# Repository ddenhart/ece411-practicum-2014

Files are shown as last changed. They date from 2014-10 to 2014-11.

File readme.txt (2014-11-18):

// ECE 411 - readme
// ddenhart@pdx.edu
// jerscott@pdx.edu
// ccarmen@pdx.edu
// nsl2@pdx.edu

---2014.10.05 nslj---
   - Initial readme added
   - Added Carmen's decision matrix to repo
   - Added Carmen's project proposals to repo
   - Added Jeremiah's project proposals to repo
   - Added Nick's project proposals to repo
   - Added Deb's project proposals to repo
   - Added personal scoring to decision matrix
  
---2014.10.05 dd---
   - Added personal scoring to decision matrix
   - updated readme 

---2014.10.06 ccarmen---
   - Added personal scoring to decision matrix
   - Added approx. cost for my proposals
   - updated readme 

---2014.10.06 jerscott---
   - Added scores and proposal costs to decision matrix
   - updated readme

---2014.10.08 nslj---
   - Added theoretical block diagram for belt project   

---2014.10.09 ccarmen---
   - Added meeting minutes on Wiki 
   - Added decision matrix 
 
---2014.10.11 dd---
   - Added color sensing proposals

---2014.10.11 jerscott---
   - Added power and vague proposals

---2014.10.11 nslj---
   - Added system overview block diagram
   - New stage folder created

---2014.10.11 ccarmen—--
   - Added LED options powerpoint

---2014.10.12 nslj---
   - Reorganized file folders to reflect latest updates (for observers)
   - Added the alternate proposals write up for HW2

---2014.10.12 jerscott---
   - Added updated Practicum Proposal

---2014.10.14 dd---
   -Added musts, shoulds and mays to the logbook wiki
   -Added datasheets & product links to the wiki
   -Filled out class forms with team members and project name
   -Added Microcontroller and Color Sensor datasheets and purchasing links to wiki
   -Added In-System Programmer links to wiki

---2014.10.14 ccarmen---
   - Added 10/11/2014 meeting minutes
   - Added RGB LED strip datasheet & product link to the wiki

---2014.10.16 ccarmen---
   - Added AVR programmer option links on Datasheet & Product Links page

---2014.10.18 ccarmen---
   - Added 10/18/2014 meeting minutes on the Wiki

---2014.10.18 dd---
   -Updated Wiki to have the T10 name and added summary
   -Added Project Proposal and Decision Matrix Pages
   -Made organized Wiki sidebar

---2014.10.19 cc---
   -Added LED output drawing to provide info for the project schematic

---2014.10.20 dd---
   - Added Color Sensor block drawing
   
---2014.10.21 cc---
   - Carmen Ciobanu implemented the new Weekly Progress Report format on the Wiki (individual and team combined)

---2014.10.22 dd---
   -Added the template pages for the individual weekly reports on the wiki
   -Filled in the past weekly reports

---2014.10.23 dd---
  - installed avr studio to start learning
  - installed winavr to start learning

---2014.10.23 jerscott---
   - Added PDS
   
---2014.10.24 dd---
   - Color sensors, Micontrollers, test RGB leds, power supply and ISP parts arrived

---2014.10.24 nslj---
   - Added schematic rough draft
   - Added brief write up on adding custom libraries to EAGLE

---2014.10.24 nslj---
  - Added meeting minues and updated WPR

---2014.10.27 jerscott---
   - Uploaded Revision 2 PDS

---2014.10.27 dd---
   - Sync'd readme and wpr's
   - breadboard power adapter component and last of other connectors arrived

---2014.10.29 nslj---
   - Added preliminary schematic for turn in
   - Updated wiki with schematic info
 
---2014.11.02 dd---
   - Sync'd readme and wpr's

---2014.11.5 nslj---
   - preliminary board layout uploaded
   - updated wiki with layout info

---2014.11.6 nslj---
   - completely rerouted board with correct size traces
   - redid components based on preliminary bill of materials
   - new switch, new capacitors!

---2014.11.06 jerscott---
   - Provided feedback for project schematic and board layout

---2014.11.07 cc---
   - Provided feedback for project schematic and board layout
   - Identified all the parts needed for our board on Digi-Key website and found new parts for the "package not available or not in stock" case
   - Created BOM with extra fields for manufacturer name, manufacturer part number, Digi-Key part number and direct links to components on Digi-Key website
   - Ordered all components on the BOM
   
---2014.11.08 dd---
   - made part names readable on the board 
   - project schedule proposal

---2014.11.08 cc—--
   - Received all board components from Digi-key
   - Printed board layout and put components on top
   - Good match 
   - Finished editing final version of BOM document

---2014.11.08 nslj---
   - final layout candidate uploaded!
     --fixed airwire @ (1.30,1.05)
     --smashed/sized some test points in Schematic
     --updated dimension layer of board for better spacing of mounting holes
     --added teamname info to both tPlace and tSilk layers
     --png screenshots of final layout candidate?

---2014.11.09 cc—--
   - Created Project Schedule document from project schedule documents provided by each team member
  
---2014.11.10 dd---
   - Reviewed and fitted the Project Schedule
   
---2014.11.15 dd---
   - Added the color sensor uml activity view

---2014.11.15 cc—--
   - Added LED Output driver protocol sequence diagram

---2014.11.16 nslj---
   - Added L0 system view block diagram
   - Added L1 system view block diagram
   - Added L0 module view for subcomponents in system view

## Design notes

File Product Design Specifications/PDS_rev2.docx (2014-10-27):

Color Sensing Infinity Mirror

Practicum for ECE 411

Team 10:

Carmen Ciobanu

Deborah Denhart

Nick Lynch-Jonely

Jeremiah Scott

CONTENTS

1. INTRODUCTION
| 1.1 Practicum Requirement | 3
| 1.2 Overview | 3
| 1.3 Project Scope | 3
2. PROJECT DESCRIPTION
| 2.1 Product Summary | 3
| 2.2 Product Requirements | 4
3. USER REQUIREMENTS
| 3.1 User Interface | 6
| 3.2 User Manual | 6
4. DELETED REQUIREMENTS | | 6
5. APPENDICES | | 6
6. REVISIONS | | 6
| 6.1 Revision Marking | 6
| 6.2 Revision History | 6

1. INTRODUCTION

1.1 Practicum Requirement

A major portion of ECE 411 is the practicum project, which requires teams of students to design, build, and test a device that uses, at a minimum, a sensor, microcontroller, and an actuator. Additional requirements were specified to teams as well. These requirements shall henceforth be referred to as “marketing requirements.” The purpose of the product (henceforth referred to as “the product”) described in this document is to fulfill all marketing requirements.

1.2 Overview

LED art is popular and marketable, with interesting pieces going for hundreds of dollars. Our project decision was made with the intention to explore this attractive market. The product will be a tabletop infinity mirror that will respond to an object placed in the proximity of the mirror based on the object’s color.

The basic concept for the product was constrained and particularized by the skills of the individual team members as well as a desire for simplicity without sacrificing the demonstration of the technical acumen of the team.

1.3 Project Scope

It is the intention of the team to fulfill all of the “Must” requirements, some of the “Should” requirements, and some of the “May” requirements provided to the team by demonstrating competency through the design and construction of the product with particular interest in the following areas: bare-metal driver and software coding, use of digital and analog actuators, and creative power solutions.

The team will research and comply with best practices and standards of engineering throughout the process of creating the product.

2. PRODUCT DESCRIPTION

2.1 Product Summary

The product will be capable of sensing color. Based on the input, the product will adjust the output of an electric light array to match the detected color and it will also output a generated audio tone ~~corresponding to the color of the object~~. The product will be powered from a wall outlet and may also be powered by a rechargeable battery.

In order to make the product affordable to build and to increase the viability of the product as a commercial item, it is the intention of the team to design the product such that the total cost of components is no more that $80.

2.2 Product Requirements

System | Marketing Requirements | Engineering Requirements | Justification
Physical | 4 | 1. The microcontroller will be mounted to a two layer PCB. A sensor may be mounted to a daughter board. | The given marketing requirements specify use of a two layer PCB for the microcontroller. Based on the color sensors researched and depending upon the physical configuration of the product, a daughter board may be required for the sensor.
| 7,11 | 2. All electronics should be enclosed within the product. | This is in keeping with the desired aesthetic of the product (a tabletop novelty) and fulfills the additional marketing requirement of being enclosed. This also helps ensure the safety of the product by enclosing any exposed electrical conductors.
Power | 2,3,9 | 1. The product should be powered by a wall outlet. | This is a simple and cost effective solution that allows the team to procure an over the counter power adapter and also grants the team the flexibility not afforded by some other solutions (USB) to power more complex outputs.
| 6,10 | 2. The product may be powered by a rechargeable battery in addition to a wall outlet. | This increases the novelty of the product while allowing the team also to demonstrate proficiency with more complex power solutions.
| 6,10 | 3. The product may be capable of being turned on and off without de-powering the product. | This increases the novelty of the product while allowing the team also to demonstrate proficiency with more complex power solutions.
| 11 | 4. The power supply should be able to supply at least 12W of power under both wall power and battery power. | Based on team research, 12W should be sufficient to supply all of the product’s power requirements. This also ensures the safety of the product by ensuring that the waste heat can de dissipated without damage to the enclosure.
Microcontroller | 3,5,8,10 | 1. The product should use a microcontroller such as the Atmel AVR ATMega328 or similar to interpret the input and control the outputs. | Use of this type of microcontroller fulfills several of the marketing requirements while also allowing the team to demonstrate proficiency in writing bare metal code. In addition, this type of microcontroller provides enough GPIO pins to give the team flexibility in choosing inputs and outputs.
Input | 1,6,8,9,10 | 1. The product should use a sensor that can detect color even when no additional source of light is present and be able to transfer this data to a microcontroller. The sensor may be a TCS34725 or similar. | This is necessary for fulfilling marketing requirements and will also allow for the demonstration of proficiency in writing device drivers.
Output | 2,5,6,8,9,10 | 1. The product should have a luminescent output that can be controlled by a microcontroller and is capable of producing a range of RGB outputs. The output should also be constrained by output of the power supply. The output may be a digital LED array or similar. | This is necessary for fulfilling marketing requirements and the overall aesthetic of the product. Research has indicated that a strand of digital LED pixels will meet these various requirements. This will also allow for demonstration of proficiency in writing device drivers.
| 2,7 | 2. The light output should have a max power rating of no greater than 10W. | Based on research of available power supplies and LED outputs, 10W should be sufficiently low power to allow for battery operation and to be safely enclosed.
| 2,6,9,10 | 3. The product should output a tone controlled by PWM that corresponds to the detected color on the input. | This adds novelty to the product and also allows for demonstration of the team’s ability to manage increased complexity.
| 2 | 4. The audio output should require no more than 2W of power. | Based on research of available power supplies, 2W should be sufficiently low power to allow for battery operation.
Software | 8,10 | 1. The product will be programmed with bare metal drivers such as I2C and SPI or similar. | This fulfills marketing requirements and allows for demonstration of team proficiency.

Base Marketing Requirements (These are MUST requirements.)

1—Have one or more inputs or sensors

2—Have one or more outputs or transducers

3—Have one or more processing modules that control some of the outputs based on the inputs

4—Use two layer PCB that is between 1 and 16 in²

5—Use components that can be hand soldered

11—The product must be safe.

Additional Marketing Requirements (These are SHOULD requirements.)

6—Be novel and interesting

7—Be packaged in an enclosure

8—Be “bare metal”

9—Have more advanced sensors and actuators

10—Demonstrate proficiencies of team members

3. USER REQUIREMENTS

3.1 User Interface

The product should be sufficiently simple that the user can operate it under normal conditions with no outside instruction. The device should be coded and constructed in such a way as to be fun for the user and rugged enough to stand up to prolonged use.

3.2 User Manual

This space shall be filled with user instruction for all conditions including those that might reasonably be encountered, but that are outside the ordinary.

4. DELETED REQUIREMENTS

System | Deletion Date | Engineering Requirements | Justification
None | None | None | None

5. APPENDICES

None.

6. REVISIONS

6.1 Revision Marking

Changes to the previous revision will be marked in the current revision. Additions and changes will be highlighted in yellow (Example) while deletions will be struck through and colored red (~~Example~~).

6.2 Revision History

Revision 1—10/23/2014: Original revision.

Revision 2—10/27/2014: Made additions and one deletion from the Product Description.

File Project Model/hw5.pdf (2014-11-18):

# T10: Color Sensing Infinity Mirror System Level Design: Functional Decomposition and UML Behavior Modeling

# Carmen Ciobanu Deborah Denhart Nick Lynch-Jonely Jeremiah Scott

1

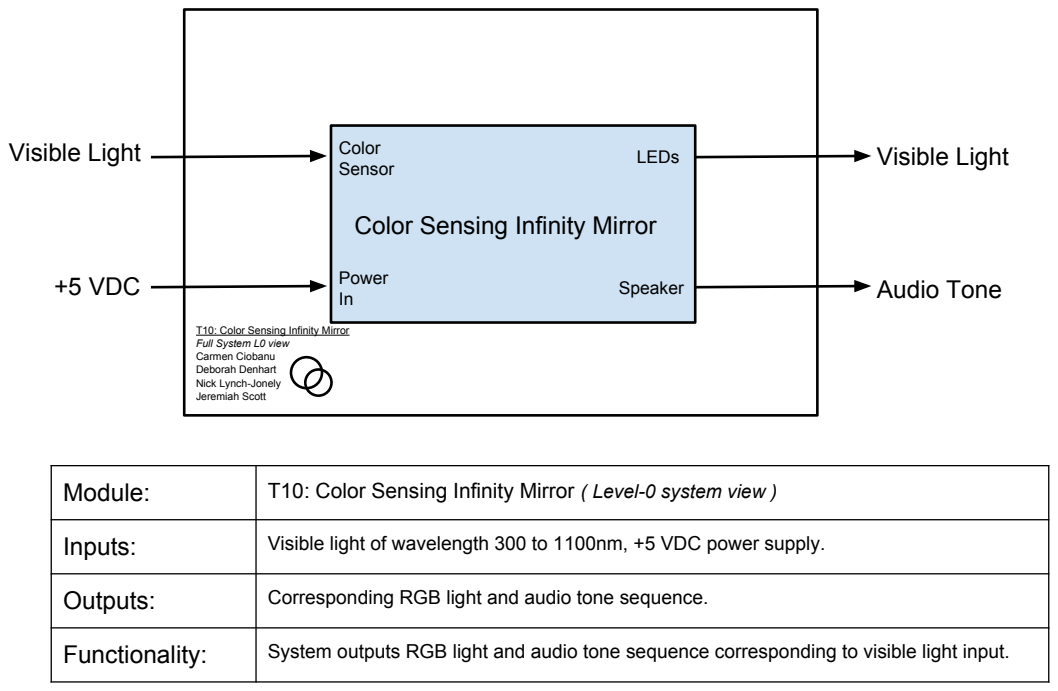
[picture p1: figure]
Color Sensor; Power In; LEDs; Speaker; Color Sensing Infinity Mirror; Visible Light; +5 VDC; Audio Tone; T10: Color Sensing Infinity Mirror Full System L0 view Carmen Ciobanu Deborah Denhart Nick Lynch-Jonely Jeremiah Scott

Module: | T10: Color Sensing Infinity Mirror ( Level-0 system view )
Inputs: | Visible light of wavelength 300 to 1100nm, +5 VDC power supply.
Outputs: | Corresponding RGB light and audio tone sequence.
Functionality: | System outputs RGB light and audio tone sequence corresponding to visible light input.

2

### Power 5V

12W

### Light Intensity

Color Sensor

Power supply

LED strip driver

Audio amplifier

Brief Description | System responds to color of ambient light input by generating a corresponding color LED output and selects a single audio tone from a bank of six corresponding audio sequences that are assigned a range of color.
Inputs | Light intensity reading: λ = 300 - 1100nm Power: 5VDC 12W
Outputs | LED emission: RGB color corresponding to light intensity input

Audio output: Tone sequence corresponding to light intensity input Microcontroller Unit

RGB LED strip

Audio out

96+1 byte
LED

### Visible Light

### Audio Tone

I²C Interface

T10: Color Sensing Infinity Mirror ( Level-1 system view )

T10: Color Sensing Infinity Mirror Full System L1 view
Carmen Ciobanu
Deborah Denhart
Nick Lynch-Jonely
Jeremiah Scott

3

### RGBC Control

Module: | T10: Color Sensor ( Level-0 module view )
Inputs: | Analog signal corresponding to detected light wavelengths of 300-1100nm, line A2 connected to white LED to assist with capturing light wavelength data. -0.5 to +3.8 VDC power supply.
Outputs: | Analog-to-digital conversion of IR filtered photodiode signal is transferred to double buffered data registers and sent to a two wire I²C serial bus directly connected to microcontroller unit, ~400kHz transmission rate.
Functionality: | 16-bit digital signal containing 4-bit representations of RGB levels plus a 4-bit clear register

# sent to an I²C interface IR filtered Photo Diodes

### Clear ADC

### Red ADC

### Green ADC

### Blue ADC

Clear Data

Red Data

Green Data

Blue Data

Interrupt

## I2C Interface

### INT

### SDA

## SCL

Level Shifted Power
Supply ~3.8V DC

# VCCAmbient Light intensity

white LED

A2

visible light

T10: Color Sensing Infinity Mirror Color Sensor L0 view
Carmen Ciobanu
Deborah Denhart
Nick Lynch-Jonely
Jeremiah Scott

4

## VCC

Module: | T10: RGB LED Strip ( Level-0 module view )
Inputs: | +5 VDC power supply (Vcc), 96+1 byte serial data, clock
Outputs: | x6 1-byte PWM channels driving x2 RGB LEDs in light range from 475 to 630nm wavelength, serial data, 1Hz clock signal
Functionality: | Drives RGB LED color from +/- 0.4V PWM signal input. Each driver chip is responsible for 2 LEDs. 96+1 bytes of information are sent to the first driver chip, 6 bytes are used for that chip and 90+1 bytes are passed on. Process continues for remaining driver chips.

### data

### clock data

### clock

### LED Current Driver

### LED Current Driver

r data

g data
b data

r data

g data
b data

### RGB LED

### RGB LED

r data

g data
b data

r data

g data
b data

### data

### clock

### x16 LED Current Driver x32 RGB LED

… x14

1

2
T10: Color Sensing Infinity Mirror RGB-LED strip L0 view
Carmen Ciobanu
Deborah Denhart
Nick Lynch-Jonely
Jeremiah Scott

5

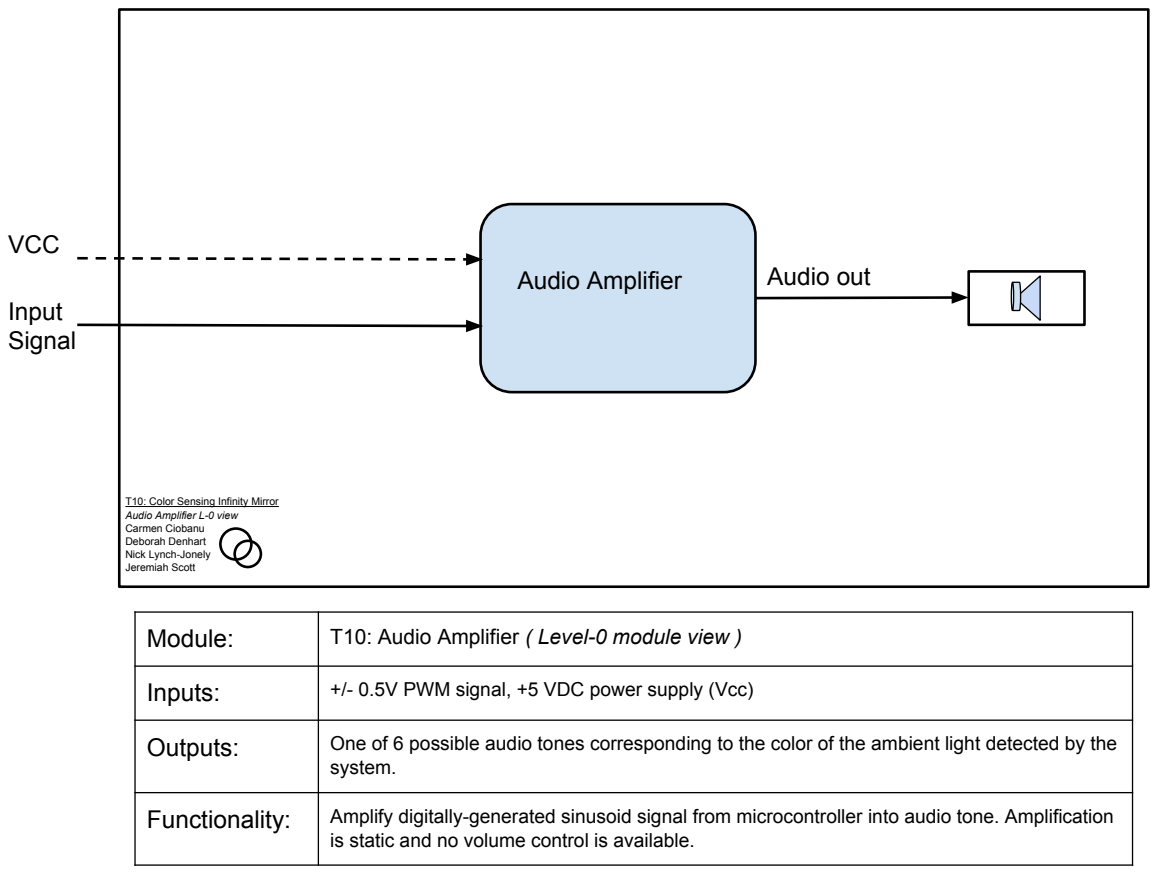
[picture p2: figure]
VCC; Input Signal; Audio Amplifier; Audio out; T10: Color Sensing Infinity Mirror Audio Amplifier L-0 view Carmen Ciobanu Deborah Denhart Nick Lynch-Jonely Jeremiah Scott

Module: | T10: Audio Amplifier ( Level-0 module view )
Inputs: | +/- 0.5V PWM signal, +5 VDC power supply (Vcc)
Outputs: | One of 6 possible audio tones corresponding to the color of the ambient light detected by the system.
Functionality: | Amplify digitally-generated sinusoid signal from microcontroller into audio tone. Amplification is static and no volume control is available.

6

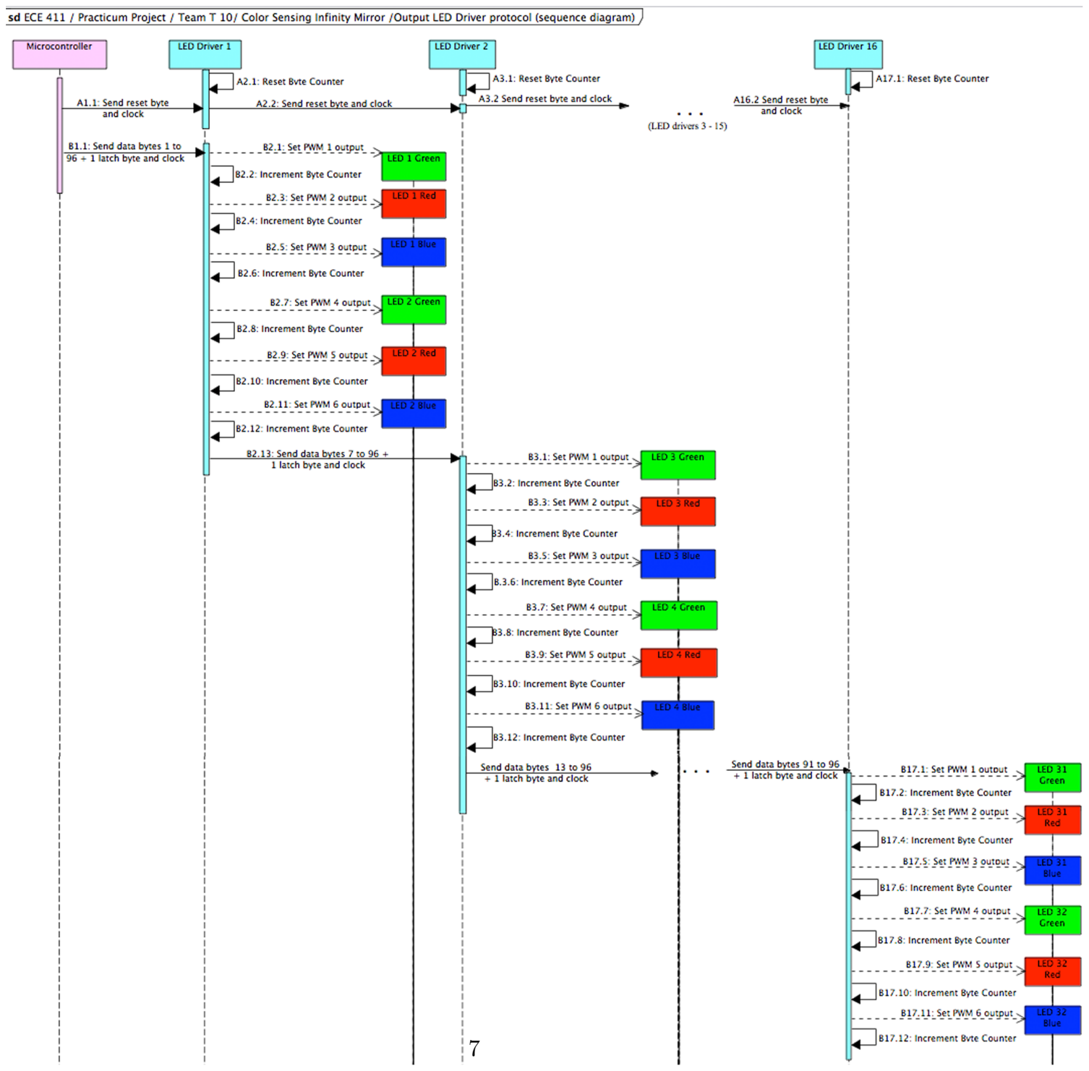
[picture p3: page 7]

7

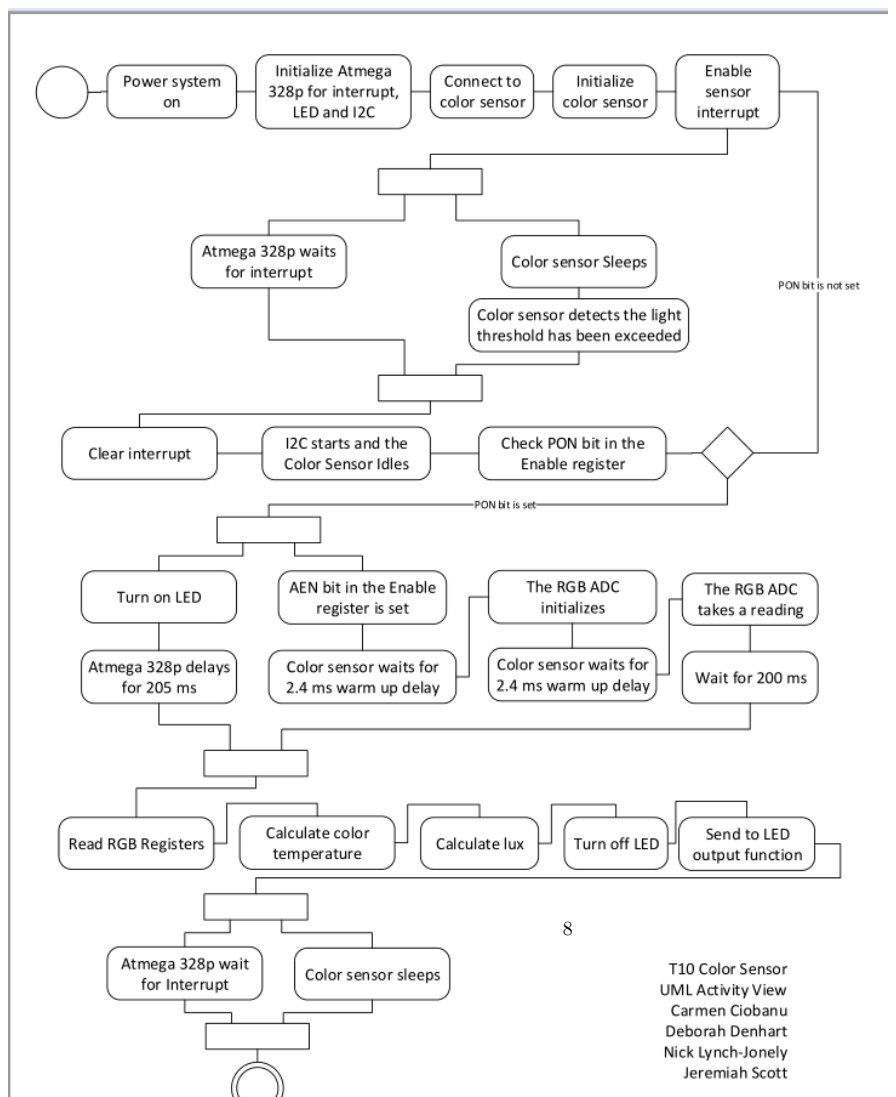
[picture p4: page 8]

8

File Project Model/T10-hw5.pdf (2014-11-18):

# T10: Color Sensing Infinity Mirror System Level Design: Functional Decomposition and UML Behavior Modeling

# Carmen Ciobanu Deborah Denhart Nick Lynch-Jonely Jeremiah Scott

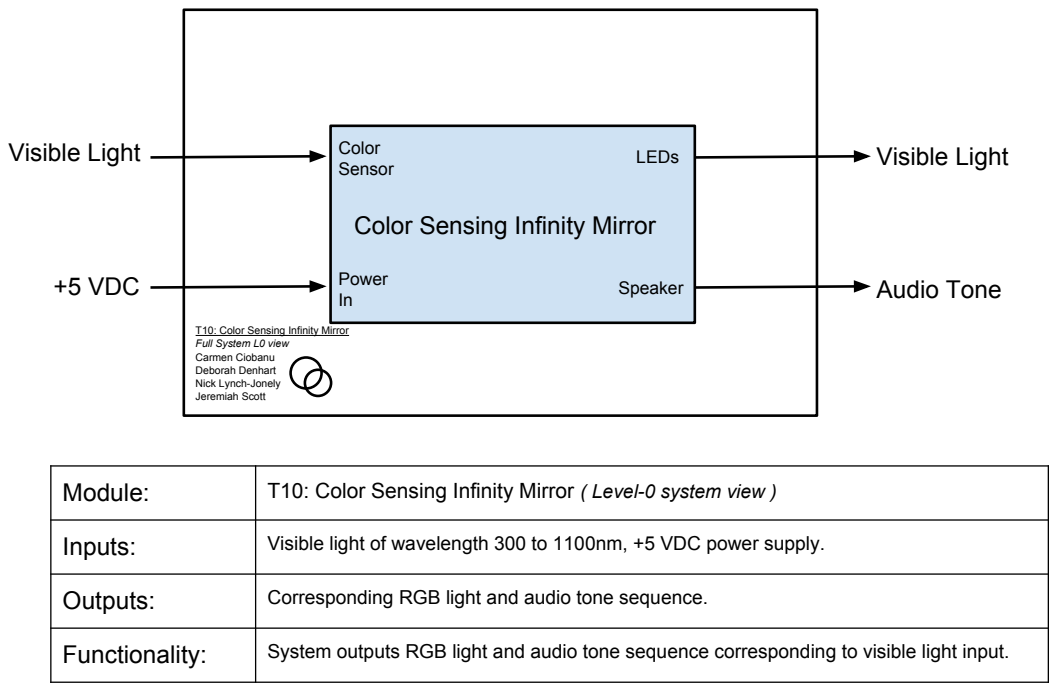
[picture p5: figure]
Color Sensor; Power In; LEDs; Speaker; Color Sensing Infinity Mirror; Visible Light; +5 VDC; Audio Tone; T10: Color Sensing Infinity Mirror Full System L0 view Carmen Ciobanu Deborah Denhart Nick Lynch-Jonely Jeremiah Scott

Module: | T10: Color Sensing Infinity Mirror ( Level-0 system view )
Inputs: | Visible light of wavelength 300 to 1100nm, +5 VDC power supply.
Outputs: | Corresponding RGB light and audio tone sequence.
Functionality: | System outputs RGB light and audio tone sequence corresponding to visible light input.

### Power 5V

12W

### Light Intensity

Color Sensor

Power supply

LED strip driver

Audio amplifier

Brief Description | System responds to color of ambient light input by generating a corresponding color LED output and selects a single audio tone from a bank of six corresponding audio sequences that are assigned a range of color.
Inputs | Light intensity reading: λ = 300 - 1100nm Power: 5VDC 12W
Outputs | LED emission: RGB color corresponding to light intensity input

Audio output: Tone sequence corresponding to light intensity input Microcontroller Unit

RGB LED strip

Audio out

96+1 byte
LED

### Visible Light

### Audio Tone

I²C Interface

T10: Color Sensing Infinity Mirror ( Level-1 system view )

T10: Color Sensing Infinity Mirror Full System L1 view
Carmen Ciobanu
Deborah Denhart
Nick Lynch-Jonely
Jeremiah Scott

### RGBC Control

Module: | T10: Color Sensor ( Level-0 module view )
Inputs: | Analog signal corresponding to detected light wavelengths of 300-1100nm, line A2 connected to white LED to assist with capturing light wavelength data. -0.5 to +3.8 VDC power supply.
Outputs: | Analog-to-digital conversion of IR filtered photodiode signal is transferred to double buffered data registers and sent to a two wire I²C serial bus directly connected to microcontroller unit, ~400kHz transmission rate.
Functionality: | 16-bit digital signal containing 4-bit representations of RGB levels plus a 4-bit clear register

# sent to an I²C interface IR filtered Photo Diodes

### Clear ADC

### Red ADC

### Green ADC

### Blue ADC

Clear Data

Red Data

Green Data

Blue Data

Interrupt

## I2C Interface

### INT

### SDA

## SCL

Level Shifted Power
Supply ~3.8V DC

# VCCAmbient Light intensity

white LED

A2

visible light

T10: Color Sensing Infinity Mirror Color Sensor L0 view
Carmen Ciobanu
Deborah Denhart
Nick Lynch-Jonely
Jeremiah Scott

## VCC

Module: | T10: RGB LED Strip ( Level-0 module view )
Inputs: | +5 VDC power supply (Vcc), 96+1 byte serial data, clock
Outputs: | x6 1-byte PWM channels driving x2 RGB LEDs in light range from 475 to 630nm wavelength, serial data, 1Hz clock signal
Functionality: | Drives RGB LED color from +/- 0.4V PWM signal input. Each driver chip is responsible for 2 LEDs. 96+1 bytes of information are sent to the first driver chip, 6 bytes are used for that chip and 90+1 bytes are passed on. Process continues for remaining driver chips.

### data

### clock data

### clock

### LED Current Driver

### LED Current Driver

r data

g data
b data

r data

g data
b data

### RGB LED

### RGB LED

r data

g data
b data

r data

g data
b data

### data

### clock

### x16 LED Current Driver x32 RGB LED

… x14

1

2
T10: Color Sensing Infinity Mirror RGB-LED strip L0 view
Carmen Ciobanu
Deborah Denhart
Nick Lynch-Jonely
Jeremiah Scott

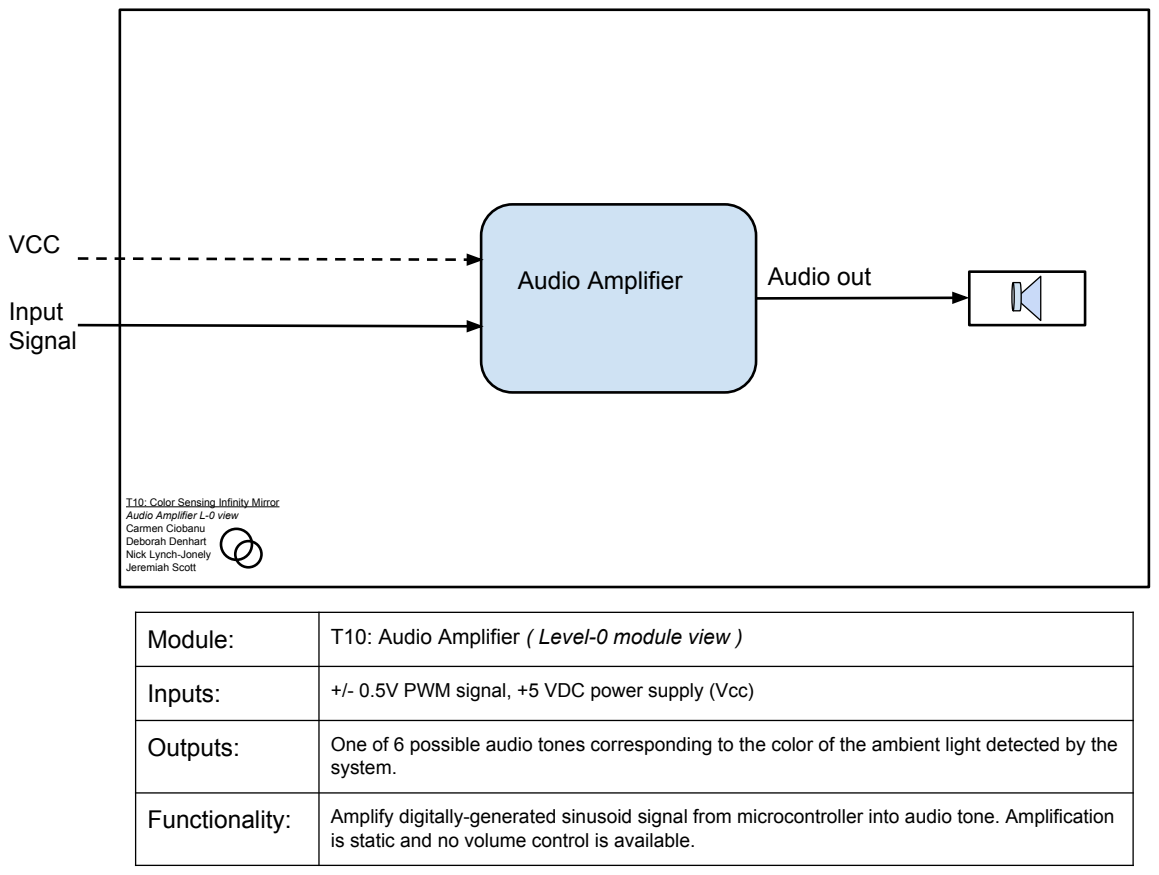
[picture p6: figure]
VCC; Input Signal; Audio Amplifier; Audio out; T10: Color Sensing Infinity Mirror Audio Amplifier L-0 view Carmen Ciobanu Deborah Denhart Nick Lynch-Jonely Jeremiah Scott

Module: | T10: Audio Amplifier ( Level-0 module view )
Inputs: | +/- 0.5V PWM signal, +5 VDC power supply (Vcc)
Outputs: | One of 6 possible audio tones corresponding to the color of the ambient light detected by the system.
Functionality: | Amplify digitally-generated sinusoid signal from microcontroller into audio tone. Amplification is static and no volume control is available.

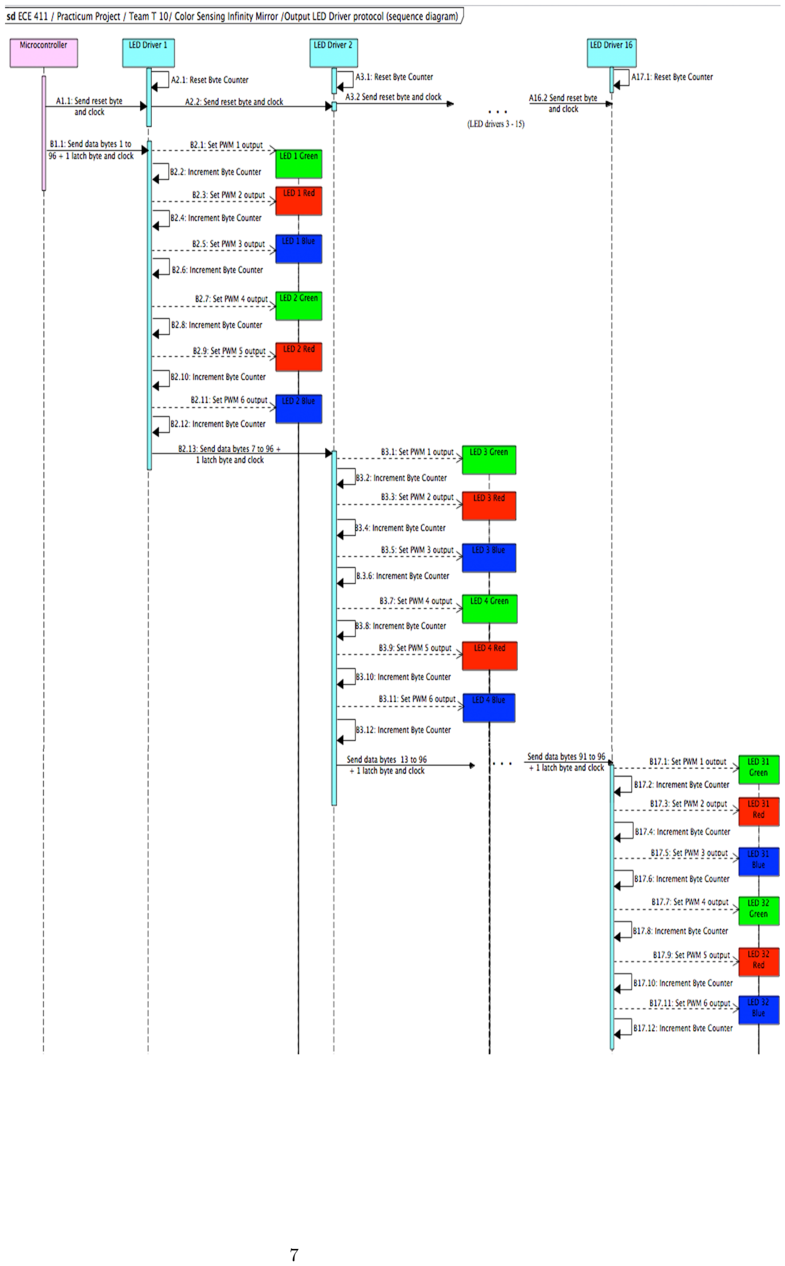
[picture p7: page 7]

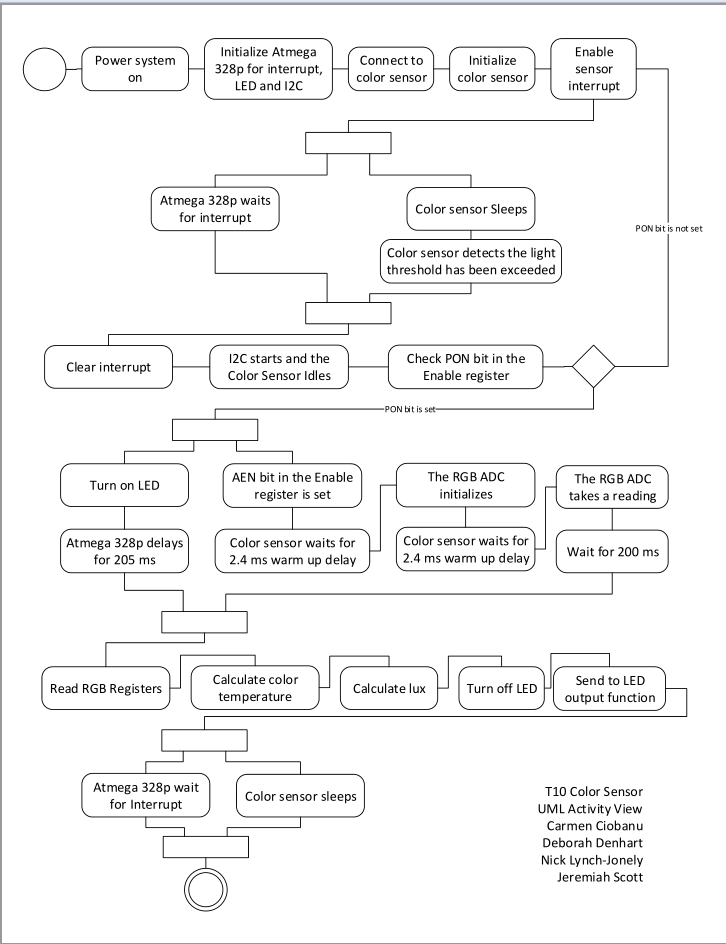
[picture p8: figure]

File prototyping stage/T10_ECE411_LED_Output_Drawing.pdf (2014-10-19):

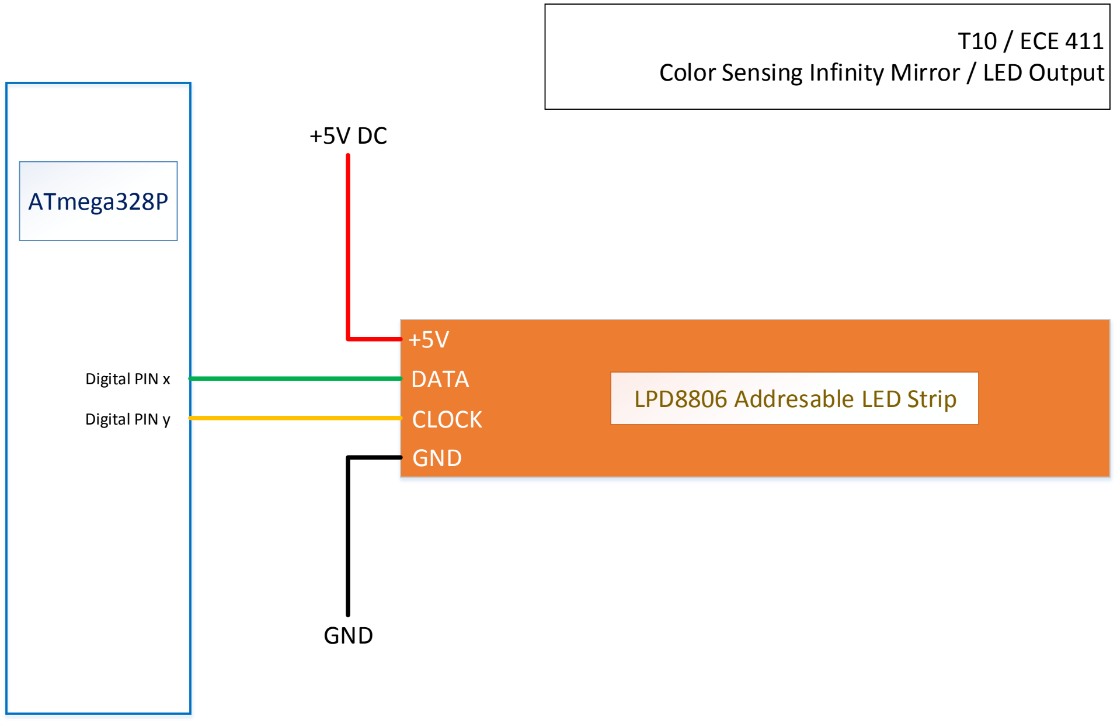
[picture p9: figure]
ATmega328P; DATA; CLOCK GND; LPD8806 Addresable LED Strip; GND; Digital PIN x; Digital PIN y; T10 / ECE 411

Color Sensing Infinity Mirror / LED Output

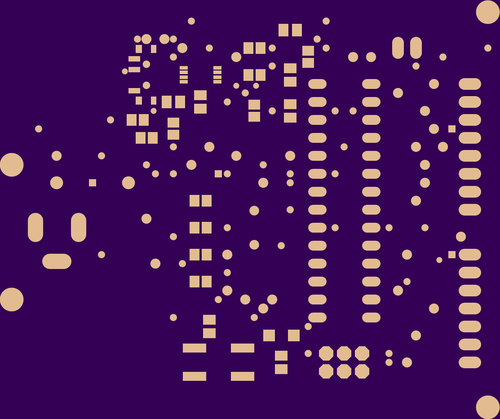
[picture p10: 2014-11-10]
Schematic/oshpark renders/topmask.png

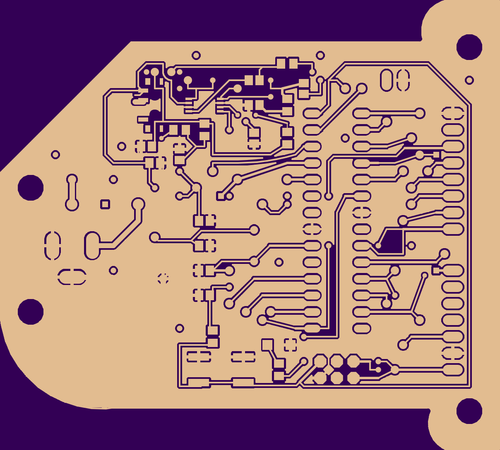
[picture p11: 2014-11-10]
Schematic/oshpark renders/toplayer.png

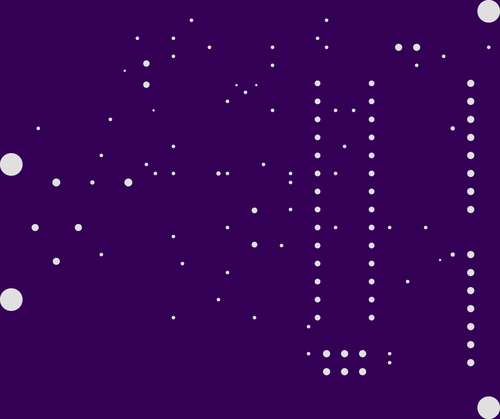
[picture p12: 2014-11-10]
Schematic/oshpark renders/drills.png

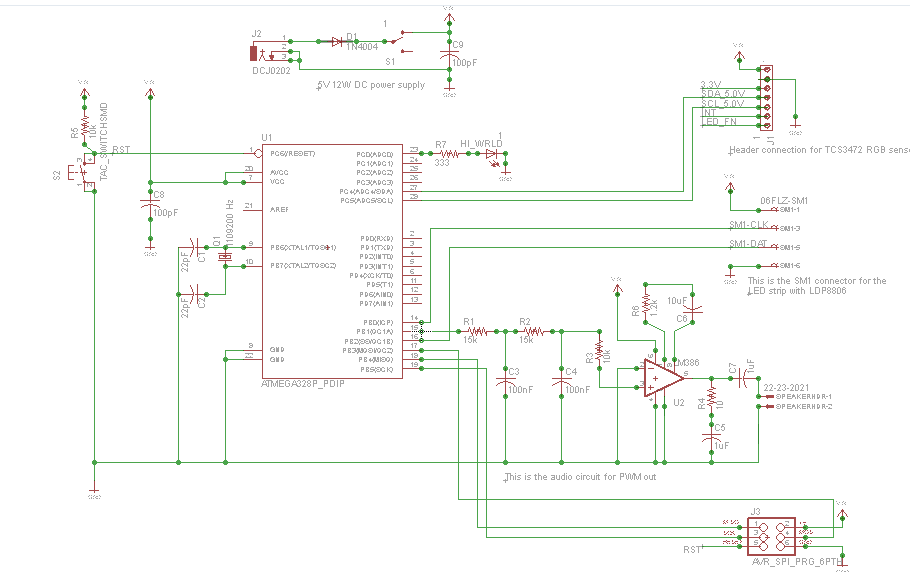
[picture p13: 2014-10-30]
Schematic/preliminaryschematic_v1_01.png

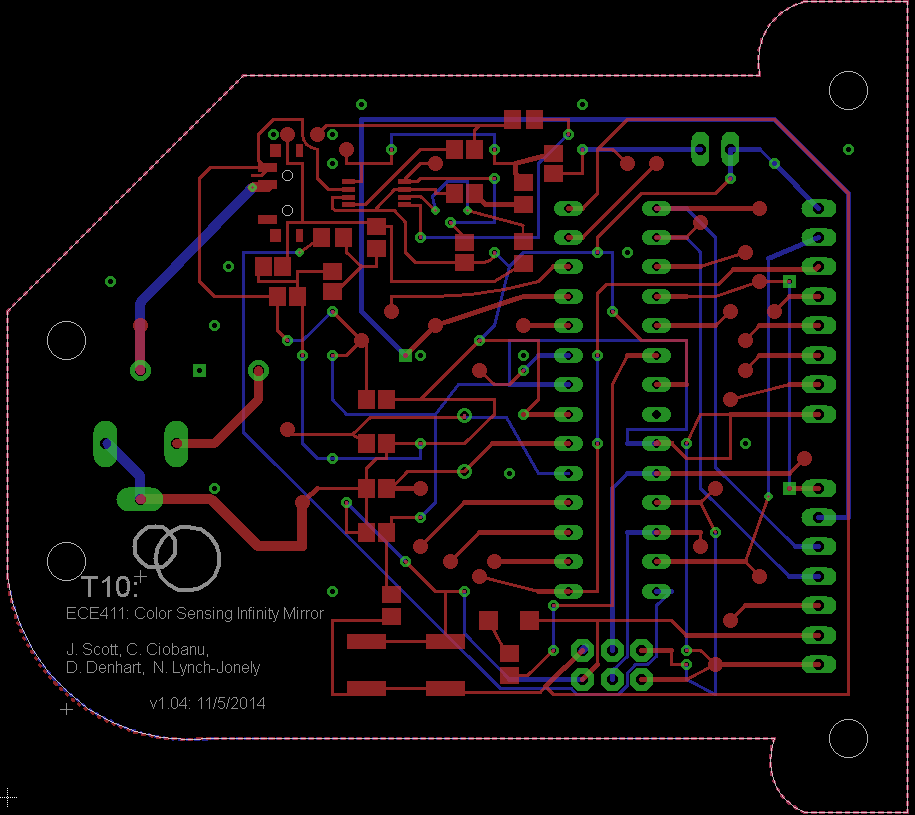
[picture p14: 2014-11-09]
Schematic/board_layout_final1.png

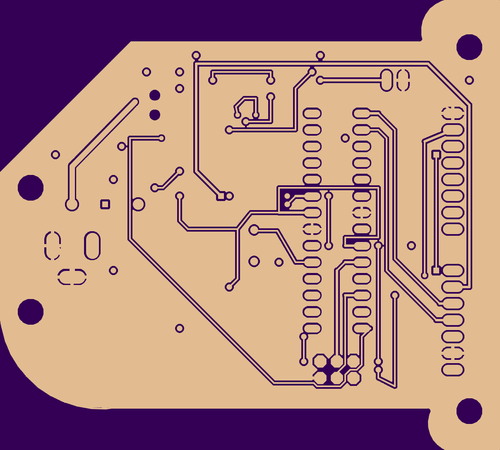
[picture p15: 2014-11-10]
Schematic/oshpark renders/bottomlayer.png

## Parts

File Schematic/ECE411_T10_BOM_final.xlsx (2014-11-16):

 |  |  |  | ECE411 Practicum T10 BOM for Infinity Mirror Project
Quantity | Part Number | Value | Package | Description | Manufacturer | Manufacturer Part Number | Distributor | Distributor Part Number | Cost Each | Cost Extended | Product Link
1 | JP1 |  | 1X08 | PIN HEADER | Sullins Connector Solutions | PPTC081LFBN-RC | Digi-Key | S7006-ND | $0.860 | $0.86 | Product Link (http://www.digikey.com/product-search/en?vendor=0&keywords=S7006-ND)
1 | HI_WRLD | 1 | SML1206 | LED | Lite-On Inc | LTST-C150KGKT | Digi-Key | 160-1404-1-ND | $0.390 | $0.39 | Product Link (http://www.digikey.com/product-detail/en/LTST-C150KGKT/160-1404-1-ND/386759)
1 | J1 | 1 | 10X07MTA | AMP connector | TE Connectivity | 640456-7 | Digi-Key | A19472-ND | $0.360 | $0.36 | Product Link (http://www.digikey.com/product-detail/en/640456-7/A19472-ND/259012)
1 | S1 | 1 | SWITCH-SPST-SMD-A | SPDT Switch | Apem Inc | MA12RTR | Digi-Key | 679-1847-1-ND | $1.100 | $1.10 | Product Link (http://www.digikey.com/product-detail/en/MA12RTR/679-1847-1-ND/1973774)
1 | R6 | 1.2k | M0805 | RESISTOR, American symbol | Panasonic | ERJ-P6WF1201V | Digi-Key | P16886CT-ND | $0.840 | $0.84 | Product Link (http://www.digikey.com/product-detail/en/ERJ-P6WF1201V/P16886CT-ND/4964925)
1 | R4 | 10 | M0805 | RESISTOR, American symbol | Vishay Dale | RCA080510R0FKEA | Digi-Key | 541-2219-1-ND | $0.400 | $0.40 | Product Link (http://www.digikey.com/product-detail/en/RCA080510R0FKEA/541-2219-1-ND/4946872)
5 | C3, C4, C8, C10, C11 | 100nF | C0805 | CAPACITOR, American symbol | Kemet | C0805C104J5RACTU | Digi-Key | 399-1171-1-ND | $0.160 | $0.80 | Product Link (http://www.digikey.com/product-detail/en/C0805C104J5RACTU/399-1171-1-ND/411446)
2 | R3, R5 | 10k | M0805 | RESISTOR, American symbol | Panasonic | ERJ-6ENF1002V | Digi-Key | P10.0KCCT-ND | $0.100 | $0.20 | Product Link (http://www.digikey.com/product-detail/en/ERJ-6ENF1002V/P10.0KCCT-ND/119248)
2 | C6, C9 | 10uF | C0805 | CAPACITOR, American symbol | Kemet | C0805C106K8PACTU | Digi-Key | 399-4925-1-ND | $0.210 | $0.42 | Product Link (http://www.digikey.com/product-detail/en/C0805C106K8PACTU/399-4925-1-ND/1090920)
2 | R1, R2 | 15k | R0805 | RESISTOR, American symbol | Panasonic | ERJ-6ENF1502V | Digi-Key | P15.0KCCT-ND | $0.100 | $0.20 | Product Link (http://www.digikey.com/product-detail/en/ERJ-6ENF1502V/P15.0KCCT-ND/119312)
1 | D1 | 1N4004 | DO41-10 | DIODE | Fairchild Semiconductors | 1N4004 | Digi-Key | 1N4004FSCT-ND | $0.180 | $0.18 | Product Link (http://www.digikey.com/product-detail/en/1N4004/1N4004FSCT-ND/1626118?WT.z_cid=ref_octopart_dkc_buynow&site=us)
2 | C5, C7 | 1uF | C0805 | CAPACITOR, American symbol | Kemet | C0805C105J3RACTU | Digi-Key | 399-10060-1-ND | $1.030 | $2.06 | Product Link (http://www.digikey.com/product-detail/en/C0805C105J3RACTU/399-10060-1-ND/3739579)
1 | SPEAKERHDR | 22-23-2021 | 22-23-2021 | .100 (2.54mm) Center Header - 2 Pin" | Molex Inc | 22232021 | Digi-Key | WM4200-ND | $0.200 | $0.20 | Product Link (http://www.digikey.com/product-search/en?x=0&y=0&lang=en&site=us&keywords=22232021)
2 | C1, C2 | 22pF | C0805 | CAPACITOR, American symbol | Kemet | C0805C220J5GACTU | Digi-Key | 399-1113-1-ND | $0.100 | $0.20 | Product Link (http://www.digikey.com/product-detail/en/C0805C220J5GACTU/399-1113-1-ND/411388)
1 | R7 | 333 | M0805 | RESISTOR, American symbol | Panasonic | ERJ-6ENF3320V | Digi-Key | P332CCT-ND | $0.100 | $0.10 | Product Link (http://www.digikey.com/product-detail/en/ERJ-6ENF3320V/P332CCT-ND/118818)
1 | Q1 | 8.192 MHz | HC49/S | CRYSTAL | TXC CORPORATION | 9B-8.192MAAJ-B | Digi-Key | 887-1262-ND | $0.390 | $0.39 | Product Link (http://www.digikey.com/product-detail/en/9B-8.192MAAJ-B/887-1262-ND/2207682)
1 | U1 | ATMEGA328P_PDIP | DIL28-3 | uC used in the Arduino | Atmel | ATMEGA328P-PU | Digi-Key | ATMEGA328P-PU-ND | $3.740 | $3.74 | Product Link (http://www.digikey.com/product-detail/en/ATMEGA328P-PU/ATMEGA328P-PU-ND/1914589)
1 | J3 | AVR_SPI_PRG_6PTH | 2X3 | AVR ISP 6 Pin | 3M | 961206-6404-AR | Digi-Key | 3M9459-ND | $0.420 | $0.42 | Product Link (http://www.digikey.com/product-detail/en/961206-6404-AR/3M9459-ND/2071500)
1 | J2 | DCJ0202 | DCJ0202 | DC POWER JACK | CUI Inc | PJ-102AH | Digi-Key | CP-102AH-ND | $1.180 | $1.18 | Product Link (http://www.digikey.com/product-search/en?vendor=0&keywords=PJ-102AH)
1 | IC1 | LM386MM-1 | MMSOP08 | Low Voltage Audio Power Amplifier | Texas Instruments | LM386MMX-1/NOPB | Digi-Key | LM386MMX-1/NOPBCT-ND | $1.020 | $1.02 | Product Link (http://www.digikey.com/product-detail/en/LM386MMX-1%2FNOPB/LM386MMX-1%2FNOPBCT-ND/3526976)
1 | S2 | TAC_SWITCHSMD | TACTILE-SWITCH-SMD | Momentary Switch | Panasonic | EVQ-Q2B03W | Digi-Key | P12932SCT-ND | $0.400 | $0.40 | Product Link (http://www.digikey.com/product-detail/en/EVQ-Q2B03W/P12932SCT-ND/762922)
 |  |  |  |  |  |  |  |  |  | $15.46

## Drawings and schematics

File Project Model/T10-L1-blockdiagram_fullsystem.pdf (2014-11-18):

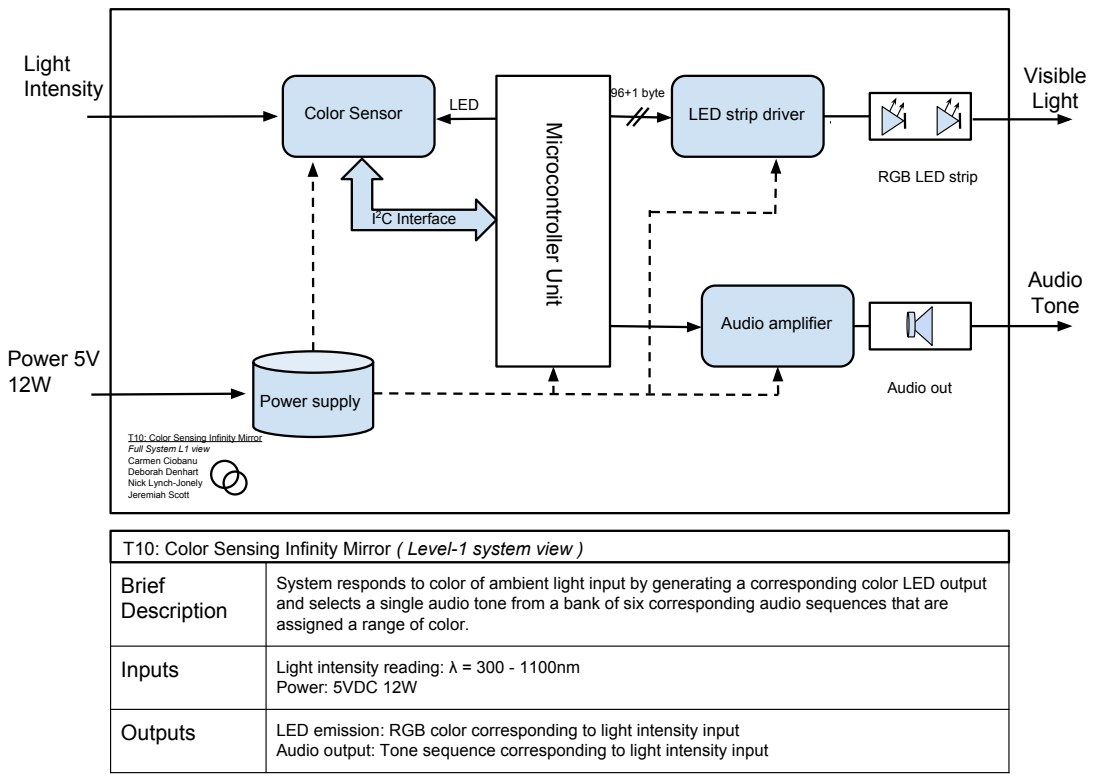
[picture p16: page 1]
Power 5V 12W; Light Intensity; Power supply; Audio amplifier; Audio out; 96+1 byte; LED; Visible Light; Audio Tone; 2C Interface

Color Sensor
Audio output: Tone sequence corresponding to light intensity input Microcontroller Unit

LED strip driver

RGB LED strip

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

T10: Color Sensing Infinity Mirror ( Level-1 system view )

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

Inputs | Light intensity reading: λ = 300 - 1100nm Power: 5VDC 12W

Outputs | LED emission: RGB color corresponding to light intensity input

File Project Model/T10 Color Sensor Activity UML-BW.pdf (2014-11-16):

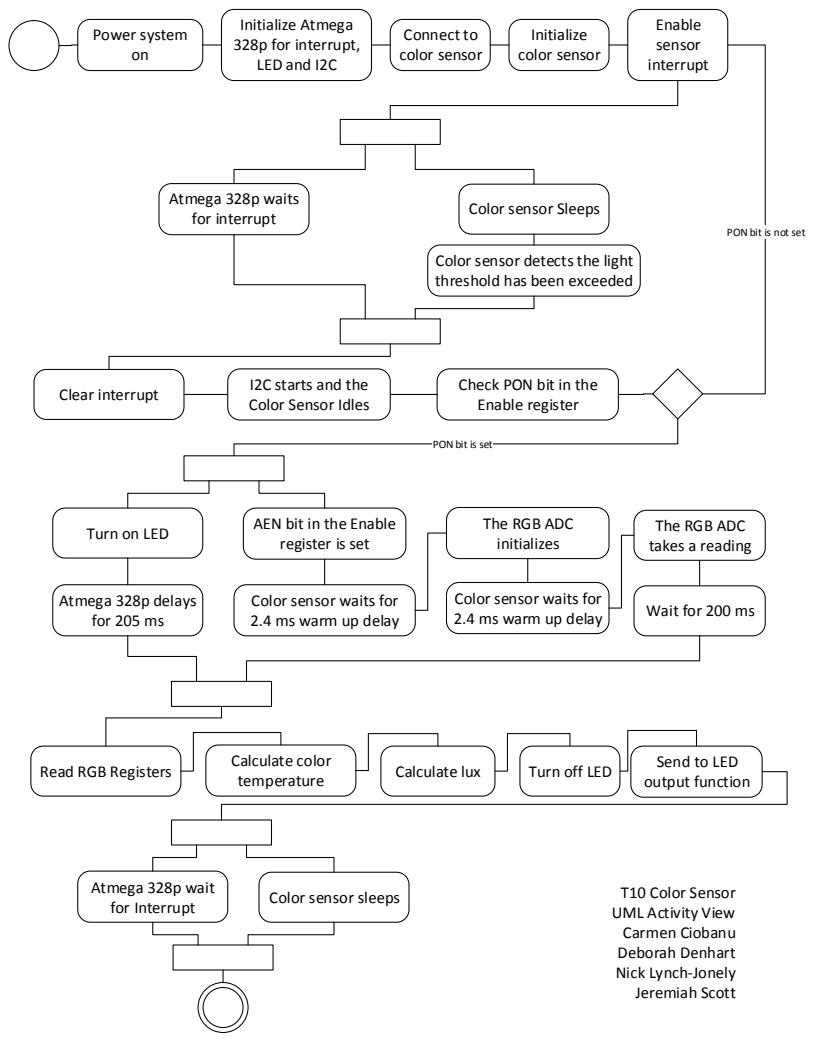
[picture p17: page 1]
Power system on; Initialize Atmega 328p for interrupt, LED and I2C; Connect to color sensor; Initialize color sensor; Enable sensor interrupt; Atmega 328p waits; for interrupt; Color sensor Sleeps; Clear interrupt; 2.4 ms warm up delay; Wait for 200 ms; Atmega 328p delays for 205 ms; Read RGB Registers; Calculate color; temperature; Calculate lux; Send to LED; output function; Atmega 328p wait; for Interrupt; Color sensor sleeps

PON bit is not set

Color sensor detects the light
threshold has been exceeded

I2C starts and the
Color Sensor Idles

Check PON bit in the
Enable register

PON bit is set

AEN bit in the Enable
register is set

The RGB ADC
initializes

takes a reading

Turn on LED

Color sensor waits for
2.4 ms warm up delay

Turn off LED

T10 Color Sensor
UML Activity View
Carmen Ciobanu
Deborah Denhart
Nick Lynch-Jonely
Jeremiah Scott

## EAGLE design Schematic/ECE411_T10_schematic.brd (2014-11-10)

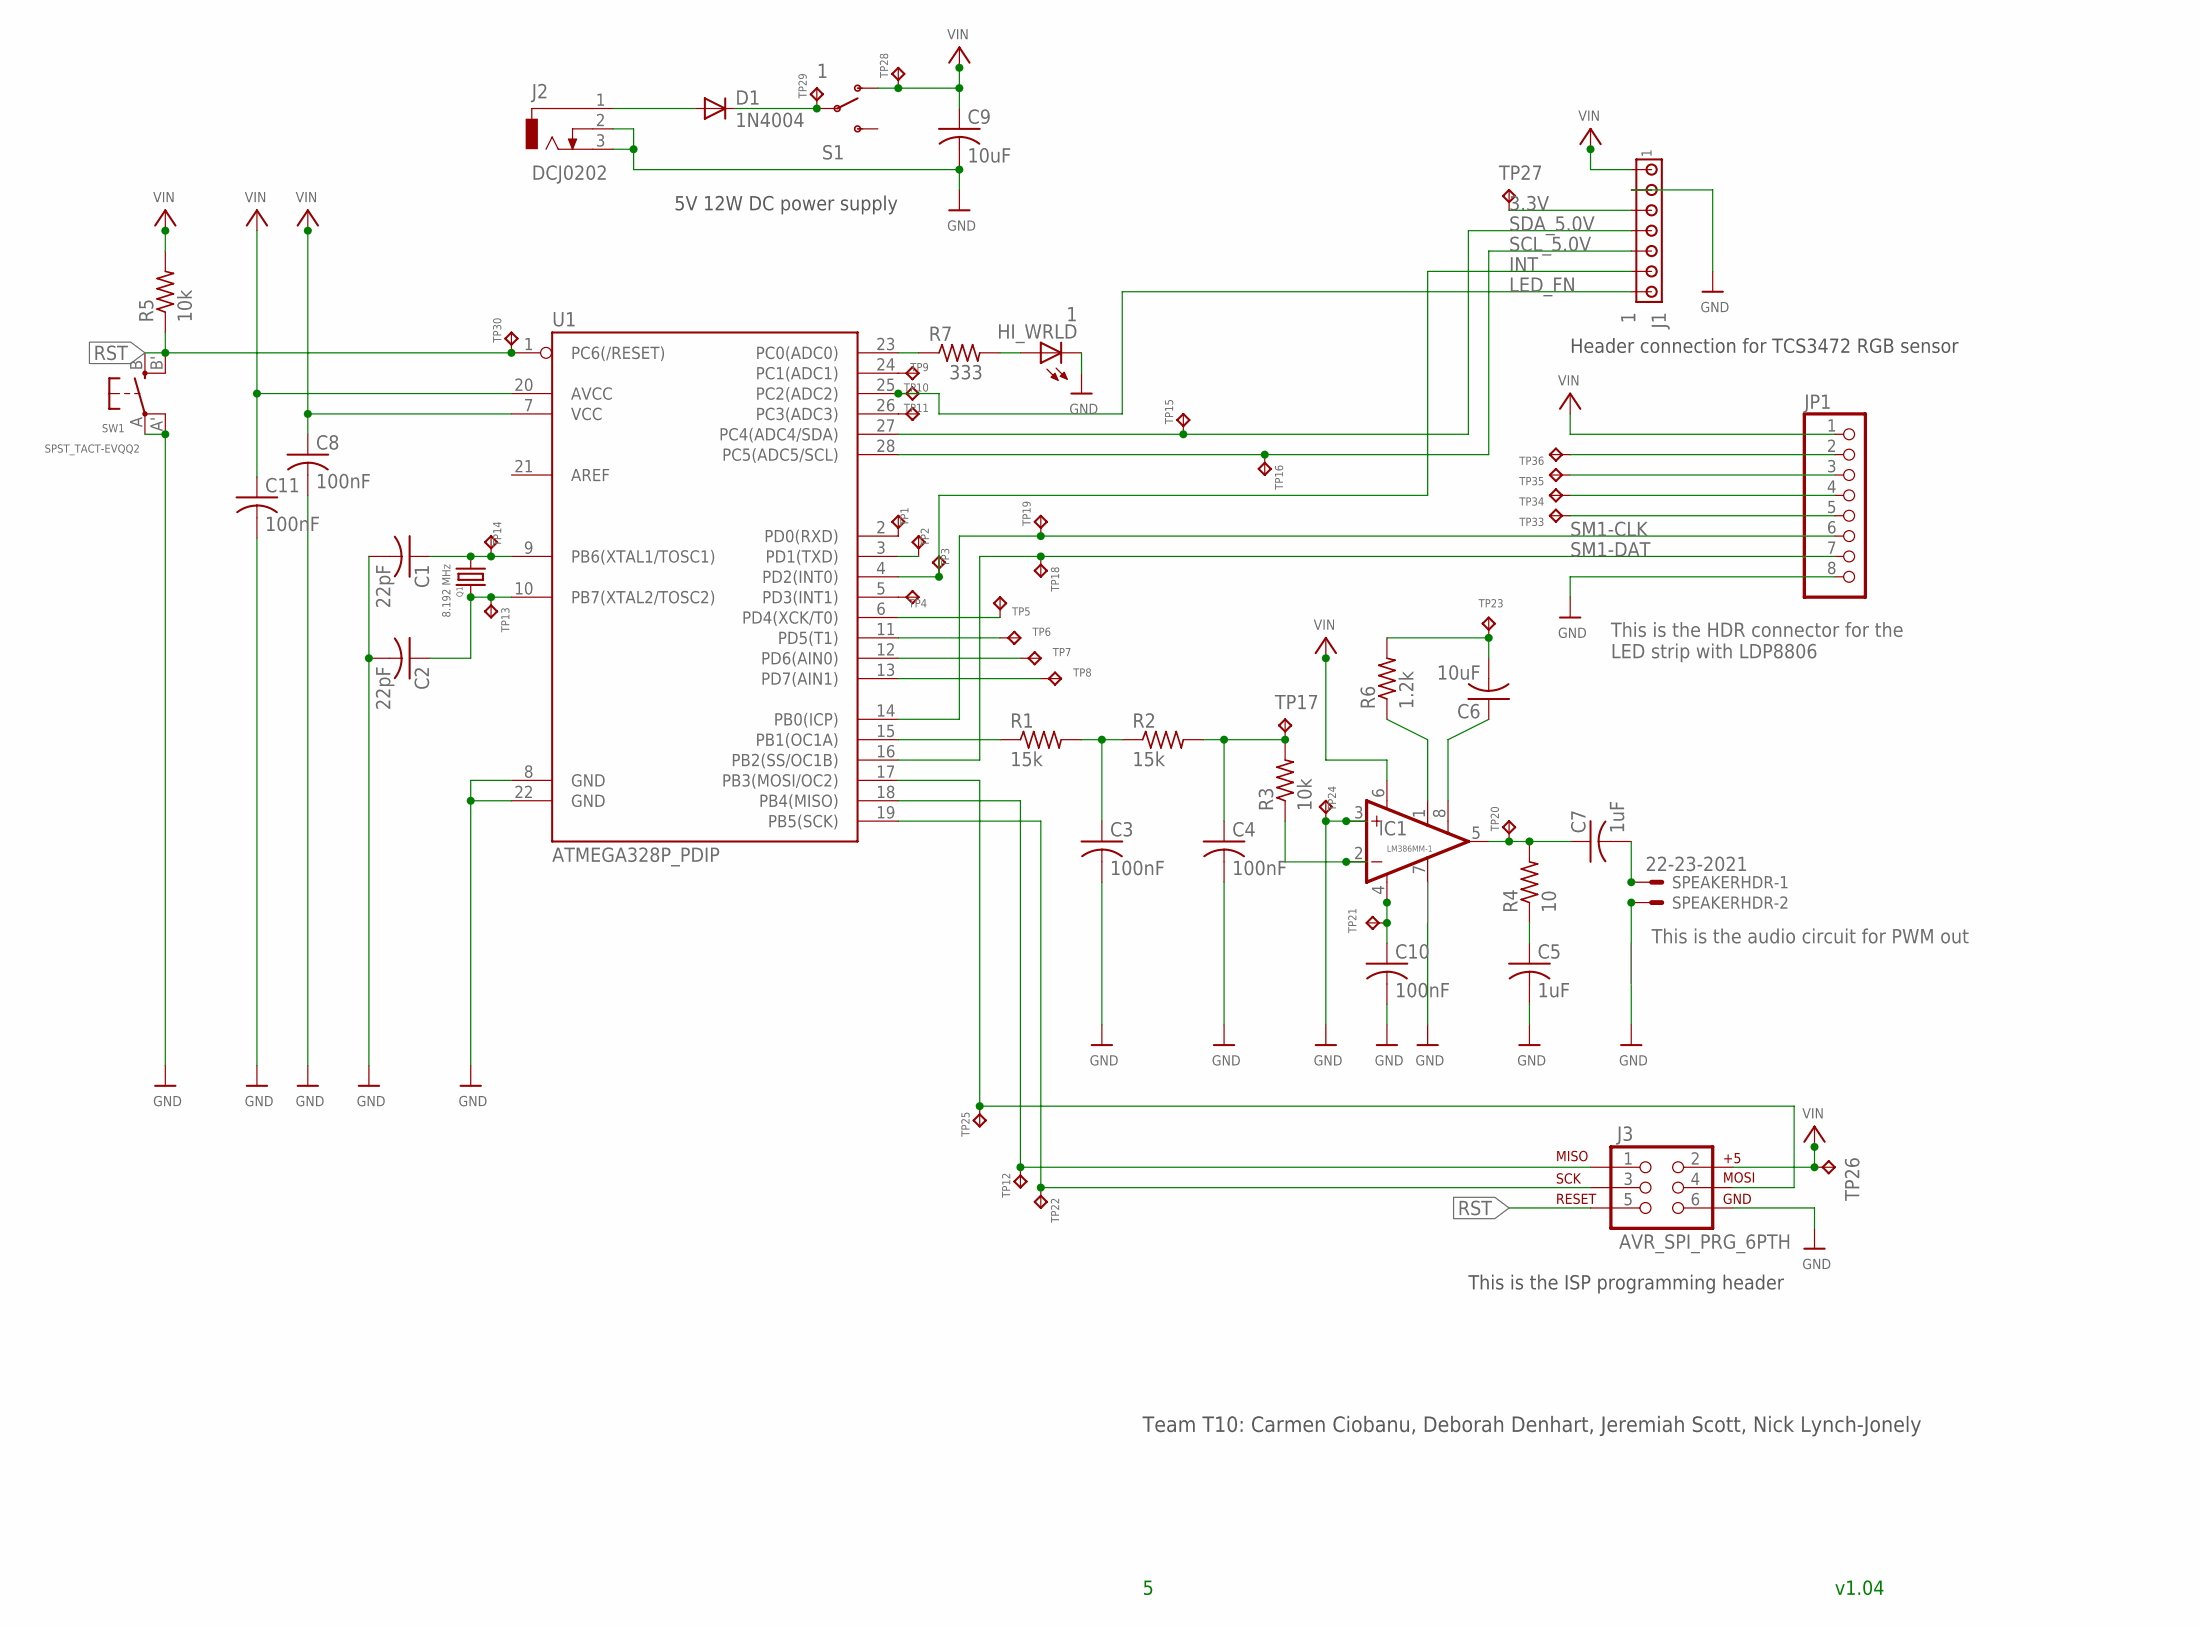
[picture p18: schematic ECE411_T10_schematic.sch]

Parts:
C1, C2: 22pF; C0805
C3, C4, C8, C10, C11: 100nF; C0805
C5, C7: 1uF; C0805
C6, C9: 10uF; C0805
D1: 1N4004; DO41-10
HI_WRLD: 1; SML1206
IC1: LM386MM-1; MMSOP08
J1: 1; 10X07MTA
J2: DCJ0202
J3: AVR_SPI_PRG_6PTH; 2X3
JP1: PINHD-1X8; 1X08
Q1: 8.192 MHz; HC49/S
R1, R2: 15k; M0805
R3, R5: 10k; M0805
R4: 10; M0805
R6: 1.2k; M0805
R7: 333; M0805
S1: 1; SWITCH-SPST-SMD-A
SPEAKERHDR: 22-23-2021
SW1: SPST_TACT-EVQQ2; EVQ-Q2
TP1, TP2, TP3, TP4, TP5, TP6, TP7, TP8, TP9, TP10, TP11, TP12, TP13, TP14, TP15, TP16, TP17, TP18, TP19, TP20, TP21, TP22, TP23, TP24, TP25, TP26, TP27, TP28, TP29, TP30, TP33, TP34, TP35, TP36: TPB1,27; B1,27
U1: ATMEGA328P_PDIP; DIL28-3

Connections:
3.3V: J1.3, TP27.TP
GND: C1.2, C2.2, C3.2, C4.2, C5.2, C8.2, C9.2, C10.2, C11.2, HI_WRLD.C, IC1.3 (+IN), IC1.7 (BYPASS), J1.2, J2.2, J2.3, J3.6, JP1.8, SPEAKERHDR.2, SW1.A, SW1.A' (P1), TP24.TP, U1.8 (GND), U1.22 (GND)
INT: J1.6, TP3.TP, U1.4 (PD2(INT0))
LED_FN: J1.7, TP10.TP, U1.25 (PC2(ADC2))
unnamed: C2.1, Q1.1, TP13.TP, U1.10 (PB7(XTAL2/TOSC2))
unnamed: C1.1, Q1.2, TP14.TP, U1.9 (PB6(XTAL1/TOSC1))
unnamed: IC1.1 (GAIN), R6.1
unnamed: R1.1, U1.15 (PB1(OC1A))
unnamed: C3.1, R1.2, R2.1
unnamed: C4.1, R2.2, R3.2, TP17.TP
unnamed: C6.1, IC1.8 (GAIN)
unnamed: IC1.2 (-IN), R3.1
unnamed: C5.1, R4.1
unnamed: R7.1, U1.23 (PC0(ADC0))
unnamed: C6.2, R6.2, TP23.TP
unnamed: C7.1, IC1.5 (OUT), R4.2, TP20.TP
unnamed: D1.A, J2.1
unnamed: C7.2, SPEAKERHDR.1
unnamed: D1.C, S1.2, TP29.TP
unnamed: TP1.TP, U1.2 (PD0(RXD))
unnamed: HI_WRLD.A, R7.2
unnamed: J3.3, TP22.TP, U1.19 (PB5(SCK))
unnamed: J3.1, TP12.TP, U1.18 (PB4(MISO))
unnamed: J3.4, TP25.TP, U1.17 (PB3(MOSI/OC2))
unnamed: TP5.TP, U1.6 (PD4(XCK/T0))
unnamed: TP2.TP, U1.3 (PD1(TXD))
unnamed: TP4.TP, U1.5 (PD3(INT1))
unnamed: TP6.TP, U1.11 (PD5(T1))
unnamed: TP7.TP, U1.12 (PD6(AIN0))
unnamed: TP8.TP, U1.13 (PD7(AIN1))
unnamed: TP9.TP, U1.24 (PC1(ADC1))
unnamed: TP11.TP, U1.26 (PC3(ADC3))
unnamed: C10.1, IC1.4 (GND), TP21.TP
unnamed: JP1.2, TP36.TP
unnamed: JP1.3, TP35.TP
unnamed: JP1.4, TP34.TP
unnamed: JP1.5, TP33.TP
RST: J3.5, R5.1, SW1.B (S), SW1.B' (S1), TP30.TP, U1.1 (PC6(/RESET))
SCL_5.0V: J1.5, TP16.TP, U1.28 (PC5(ADC5/SCL))
SDA_5.0V: J1.4, TP15.TP, U1.27 (PC4(ADC4/SDA))
SM1-CLK: JP1.6, TP19.TP, U1.14 (PB0(ICP))
SM1-DAT: JP1.7, TP18.TP, U1.16 (PB2(SS/OC1B))
VIN: C8.1, C9.1, C11.1, IC1.6 (VS), J1.1, J3.2, JP1.1, R5.2, S1.1 (O), TP26.TP, TP28.TP, U1.7 (VCC), U1.20 (AVCC)

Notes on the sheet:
This is the HDR connector for the LED strip with LDP8806
This is the audio circuit for PWM out
5V 12W DC power supply
Header connection for TCS3472 RGB sensor
Team T10: Carmen Ciobanu, Deborah Denhart, Jeremiah Scott, Nick Lynch-Jonely
v1.04
This is the ISP programming header

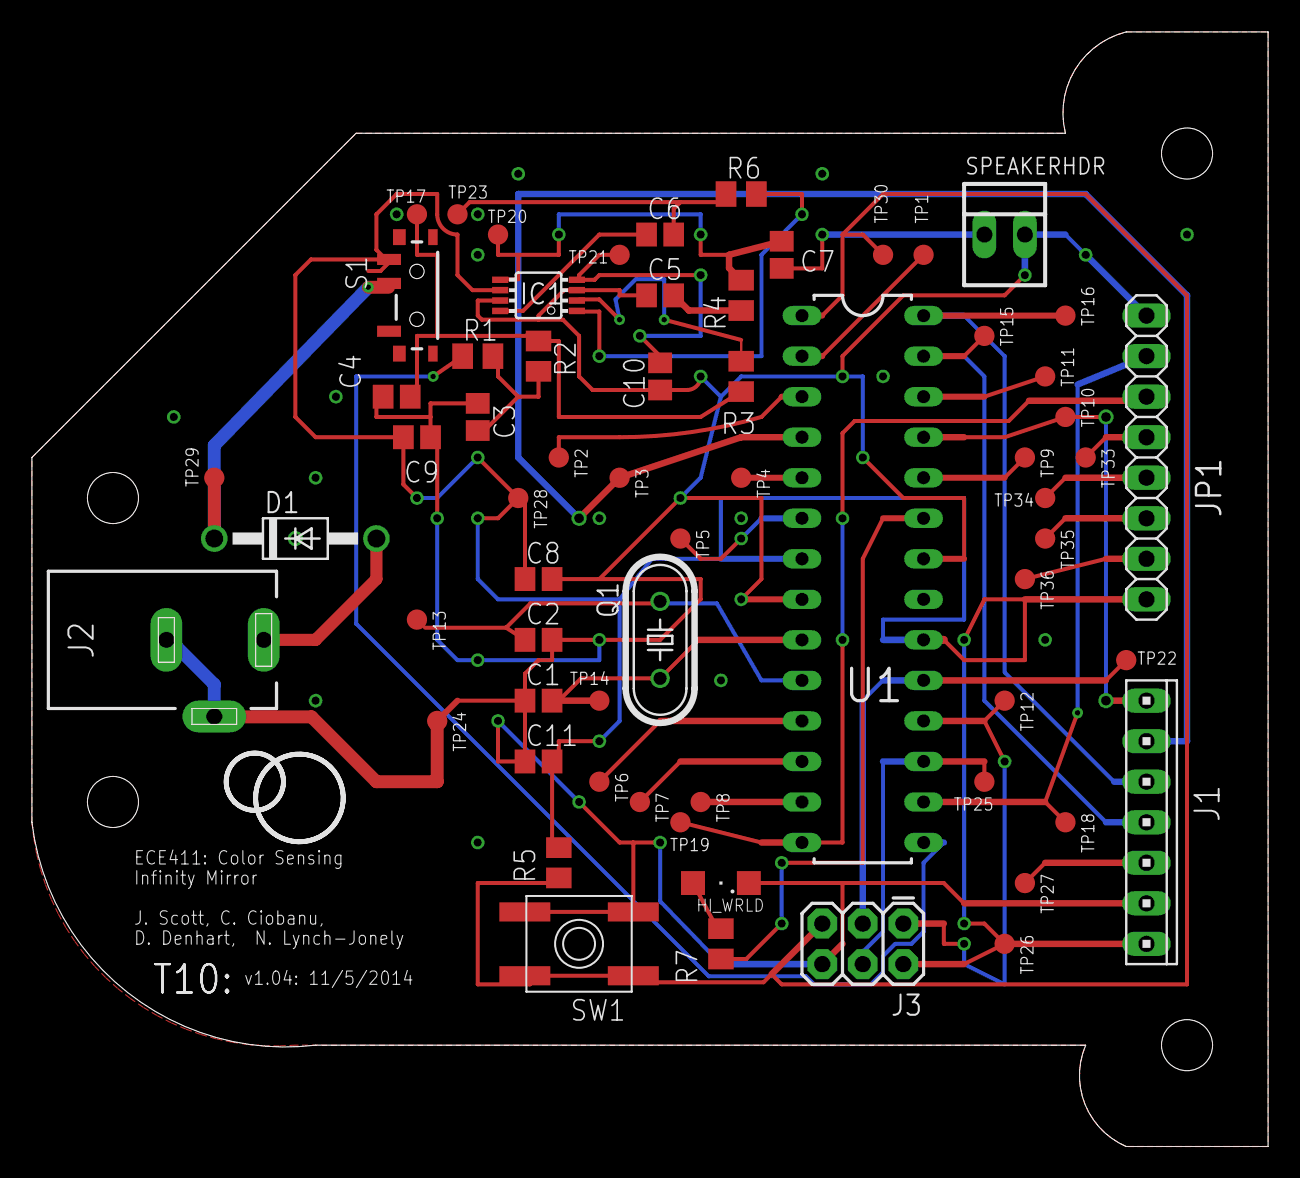
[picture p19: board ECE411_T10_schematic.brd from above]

Board: 2 copper layers, 77.5 x 69.8 mm, 64 parts (0 on the bottom side), 43 nets.

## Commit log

2014-10-19 LED Output Drawing
    LED Output Drawing for preliminary schematic
2014-10-19 LED Output Photo
    LED Output Photo to reference in the Wiki
2014-10-20 Color Sensor diagram
2014-10-24 added schematic
    t10_schem
    [t10_schem.sch]
2014-10-24 schematic.png
    terrible first draft, but the parts are there
2014-10-29 official preliminary schematic
    v1.01
    [t10_schem.sch]
2014-10-29 update readme
    readme updat for preliminary schematic
2014-10-29 relabeled schematic name for turn in
    added issues text layer
    [ECE411_T10_schematic.sch]
2014-10-30 revisions
    some quick revisions and cleanup after lecture 10/29
    [ECE411_T10_schematic.sch]
2014-10-30 remove old schematic
    [t10_schem.sch]
2014-10-30 schematic: update pngs
2014-11-05 preliminary board layout
    very preliminary
    [ECE411_T10_schematic.brd, ECE411_T10_schematic.sch]
2014-11-06 layout preliminary final
    [ECE411_T10_schematic.brd, ECE411_T10_schematic.sch]
2014-11-06 reran DRC
    errors from vias.. what even happened to my ground plane. ugh.
    [ECE411_T10_schematic.brd]
2014-11-06 adding *.pn of prelim board layout
    prelim board layout
    [ECE411_T10_schematic.brd]
2014-11-07 Preliminary board 2: electric boogaloo
    completely rerouted the board with the correct size traces!
    [ECE411_T10_schematic.brd, ECE411_T10_schematic.sch]
2014-11-07 new board layout screenshot
    *.png update of the new board
2014-11-08 made the board part names readable
    [ECE411_T10_schematic.brd]
2014-11-09 Final BOM
    Final Bill of Materials document
    [ECE411_T10_BOM_final.xlsx]
2014-11-09 final layout candidate?
    - fixed airwire @ (1.30, 1.05)
    - smashed/sized some test points on Schematic
    - updated dimension layer of board layout for better spacing of mounting
    holes
    - added team name info to both tPlace and tSilk layers
    - png screenshots of final board layout candidate?
    [ECE411_T10_schematic.brd, ECE411_T10_schematic.sch]
2014-11-09 schem_final png?
    final candidate for schematic
2014-11-09 more board edits - new pngs
    - moved test pad #14 as it was inaccessible
    - rerouted R6 R3 R4 for tKeepout
    - smash/resized some test points
    - updated pngs
    [ECE411_T10_schematic.brd]
2014-11-09 layout/schematic changes
    - rerouted INT to PD2
    - rerouted LED_FN to PC2
    - increased trace size around pad connections
    [ECE411_T10_schematic.brd, ECE411_T10_schematic.sch]
2014-11-09 crisis averted
    updated pngs of layout/schematic changes
    [ECE411_T10_schematic.brd]
2014-11-09 OSHpark renders
    board is sent!
    [ECE411_T10_schematic.brd]
2014-11-16 color sensor uml
2014-11-16 LED Output Driver protocol
    LED Output Driver protocol sequence diagram and updated BOM
    [ECE411_T10_BOM_final.xlsx]

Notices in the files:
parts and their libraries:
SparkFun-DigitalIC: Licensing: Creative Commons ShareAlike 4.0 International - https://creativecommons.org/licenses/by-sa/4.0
